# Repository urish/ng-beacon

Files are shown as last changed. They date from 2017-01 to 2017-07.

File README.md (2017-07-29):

# ng-beacon

[Physical Web Beacon](https://medium.com/@urish/exploring-the-physical-web-without-buying-beacons-efae51e36c2e) shaped after the [Angular](https://angular.io) logo with JavaScript support

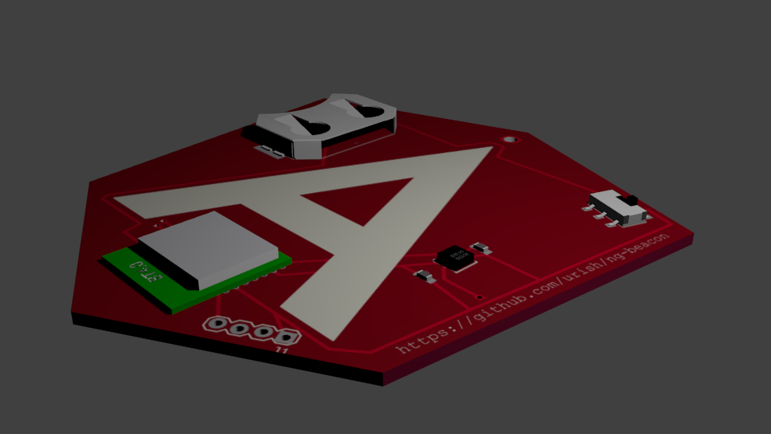
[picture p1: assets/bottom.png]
ng-beacon bottom view


Copyright (C) 2016, 2017 Uri Shaked

## Build your own beacon

Check out the [BOM](BOM.md) file for the list of materials. In addition, you need to get the [PCB](hardware/) printed, I got mine from [PCBWay](http://www.pcbway.com).

## Features

- Physical Web (Eddystone) Beacon
- iBeacon
- Built-in [JavaScript Interpreter](https://www.espruino.com/Reference)
- Fully programmable via JavaScript
- Over-the-air firmware updates
- Prototyping area where you can add your own sensors and extend the board
- Runs of CR2032 / CR2024 coin cell battery, can last for several months
- Built in LED and push button

## Hardware
The board uses the [nRF52832 chip](https://www.nordicsemi.com/eng/Products/Bluetooth-low-energy/nRF52832), which has the following features:

- 32-bit ARM Cortex-M4F Processor running at 64MHz
- 512kB flash + 64kB RAM
- Bluetooth 5 support, up to 2MBPS
- Up to +4dBm output power, -96dBm sensitivity
- 3 PWM, 3 SPI, 2 I²C, Serial UART

## Code samples

Configure the built-in button to control the LED:

    setWatch(() => LED1.toggle(), BTN1, { 
      repeat: true,
      edge: 'falling', 
      debounce: 100
    });

[More code samples](examples/)

## Firmware

The current firmware is based on [Espruino](espruino.com). The latest source code [can be found here](https://github.com/urish/Espruino/tree/ng-beacon), and the most recent firmware build can be found in [this repo](https://github.com/urish/ng-beacon-firmware).

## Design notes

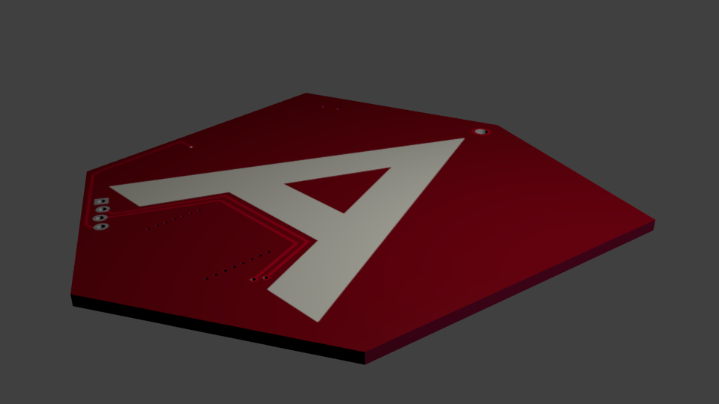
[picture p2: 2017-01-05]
assets/top.png

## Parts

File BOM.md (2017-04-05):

# ng-beacon BOM

| Name | Quantity | Price | Order Link | Comment |
|---|---|---|---|---|
| PTR5618 | 1 | 4.65$ | [Taobao](https://world.taobao.com/item/541222748619.htm?spm=a312a.7700714.0.0.PJ33KO#detail) | BLE + MCU |
| SMD Tab CR2032 Battery Holder (SMD) | 1 | 0.24$ | [AliExpress](https://www.aliexpress.com/item/50pcs-SMD-Tab-20mm-CR2032-2032-Battery-Button-Cell-Holder-Coin-Cell-Retainer-Battery-Holder-surface/32732961416.html) |  |
| DPDT Switch | 1 | 0.16$ | [AliExpress](https://www.aliexpress.com/item/100-pcs-Miniature-Slide-Switch-6-Pin-2P2T-DPDT-ON-ON-Surface-Mount-SMT-SMD-PCB/32759082251.html) |  |
| CR2032 Battery | 1 | 0.19$ | [AliExpress](https://www.aliexpress.com/item/10pcs-lot-CR2032-Lithium-Button-Cell-Batteries-ECR2032-DL2032-KCR2032-EE6227-3V-220mAh-Rohs/32648145261.html) |  |
| SHT20 | Optional | 1.7$ | [AliExpress](https://www.aliexpress.com/item/10pcs-lot-SHT20-Temperature-And-Humidity-Sensor/1916310064.html) | Temperature Sensor |

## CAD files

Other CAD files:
models/DFN6_SHT.skp
models/PTR5518.skp

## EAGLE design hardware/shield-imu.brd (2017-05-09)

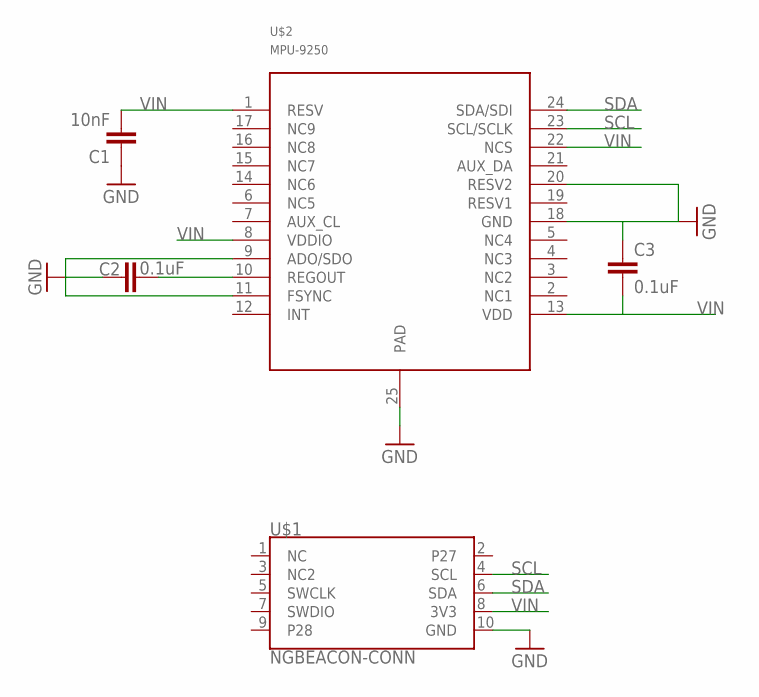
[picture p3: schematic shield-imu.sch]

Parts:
C1: 10nF; 0603-CAP
C2, C3: 0.1uF; 0603-CAP
U$1: NGBEACON-CONN; 2X5-PTH-1.27MM
U$2: MPU-9250; LEAD-QFN24

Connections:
GND: C1.1, C2.1, C3.1, U$1.10 (GND), U$2.9 (ADO/SDO), U$2.11 (FSYNC), U$2.18 (GND), U$2.20 (RESV2), U$2.25 (PAD)
unnamed: C2.2, U$2.10 (REGOUT)
SCL: U$1.4 (SCL), U$2.23 (SCL/SCLK)
SDA: U$1.6 (SDA), U$2.24 (SDA/SDI)
VIN: C1.2, C3.2, U$1.8 (3V3), U$2.1 (RESV), U$2.8 (VDDIO), U$2.13 (VDD), U$2.22 (NCS)

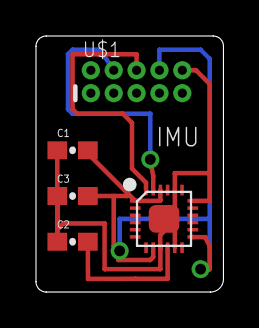
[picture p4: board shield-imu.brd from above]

Board: 2 copper layers, 10.4 x 14.2 mm, 5 parts (0 on the bottom side), 5 nets.

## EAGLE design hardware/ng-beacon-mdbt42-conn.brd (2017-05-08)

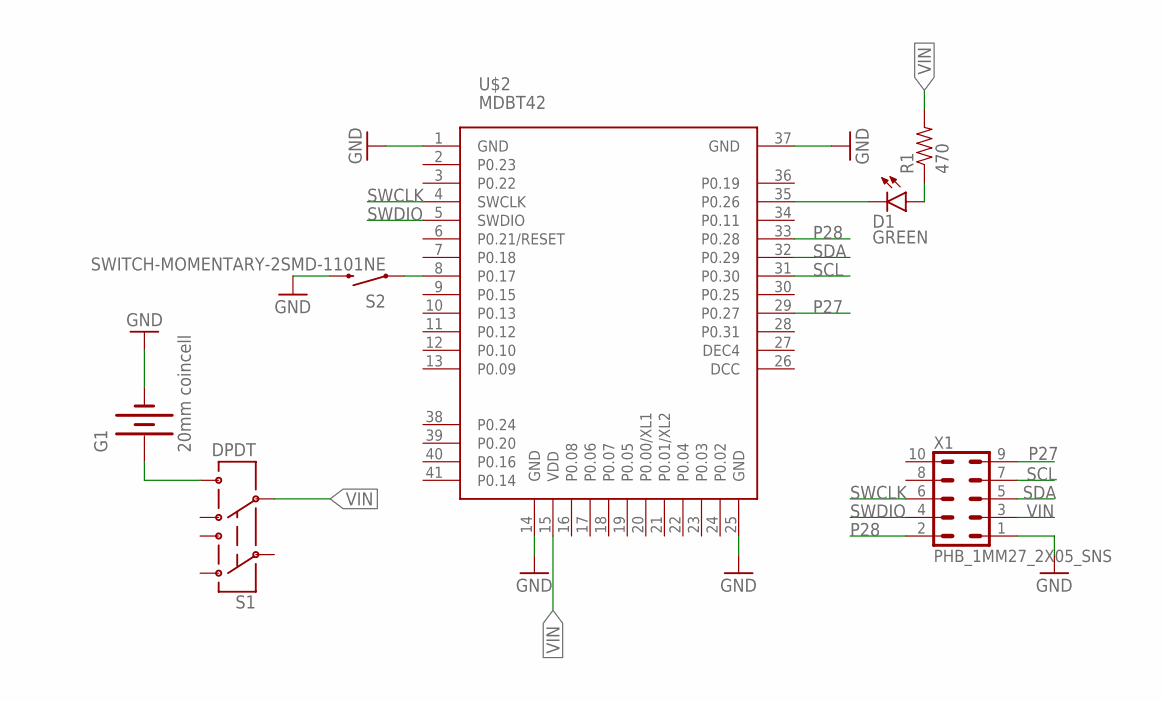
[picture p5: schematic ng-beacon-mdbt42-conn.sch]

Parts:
D1: GREEN; LED-0603
G1: 20mm coincell; BATTCON_20MM_4LEGS
R1: 470; 0603-RES
S1: DPDT; AYZ0202
S2: SWITCH-MOMENTARY-2SMD-1101NE; TACTILE-SWITCH-1101NE
U$2: MDBT42
X1: PHB_1MM27_2X05_SNS

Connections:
GND: G1.NEGATIVE (-), S2.2, U$2.1 (GND), U$2.14 (GND), U$2.25 (GND), U$2.37 (GND), X1.1
unnamed: G1.POSITIVE@1 (+), G1.POSITIVE@2 (+), G1.POSITIVE@3 (+), G1.POSITIVE@4 (+), S1.6
unnamed: S2.1, U$2.8 (P0.17)
unnamed: D1.C, U$2.35 (P0.26)
unnamed: D1.A, R1.1
P27: U$2.29 (P0.27), X1.9
P28: U$2.33 (P0.28), X1.2
SCL: U$2.31 (P0.30), X1.7
SDA: U$2.32 (P0.29), X1.5
SWCLK: U$2.4 (SWCLK), X1.6
SWDIO: U$2.5 (SWDIO), X1.4
VIN: R1.2, S1.5, U$2.15 (VDD), X1.3

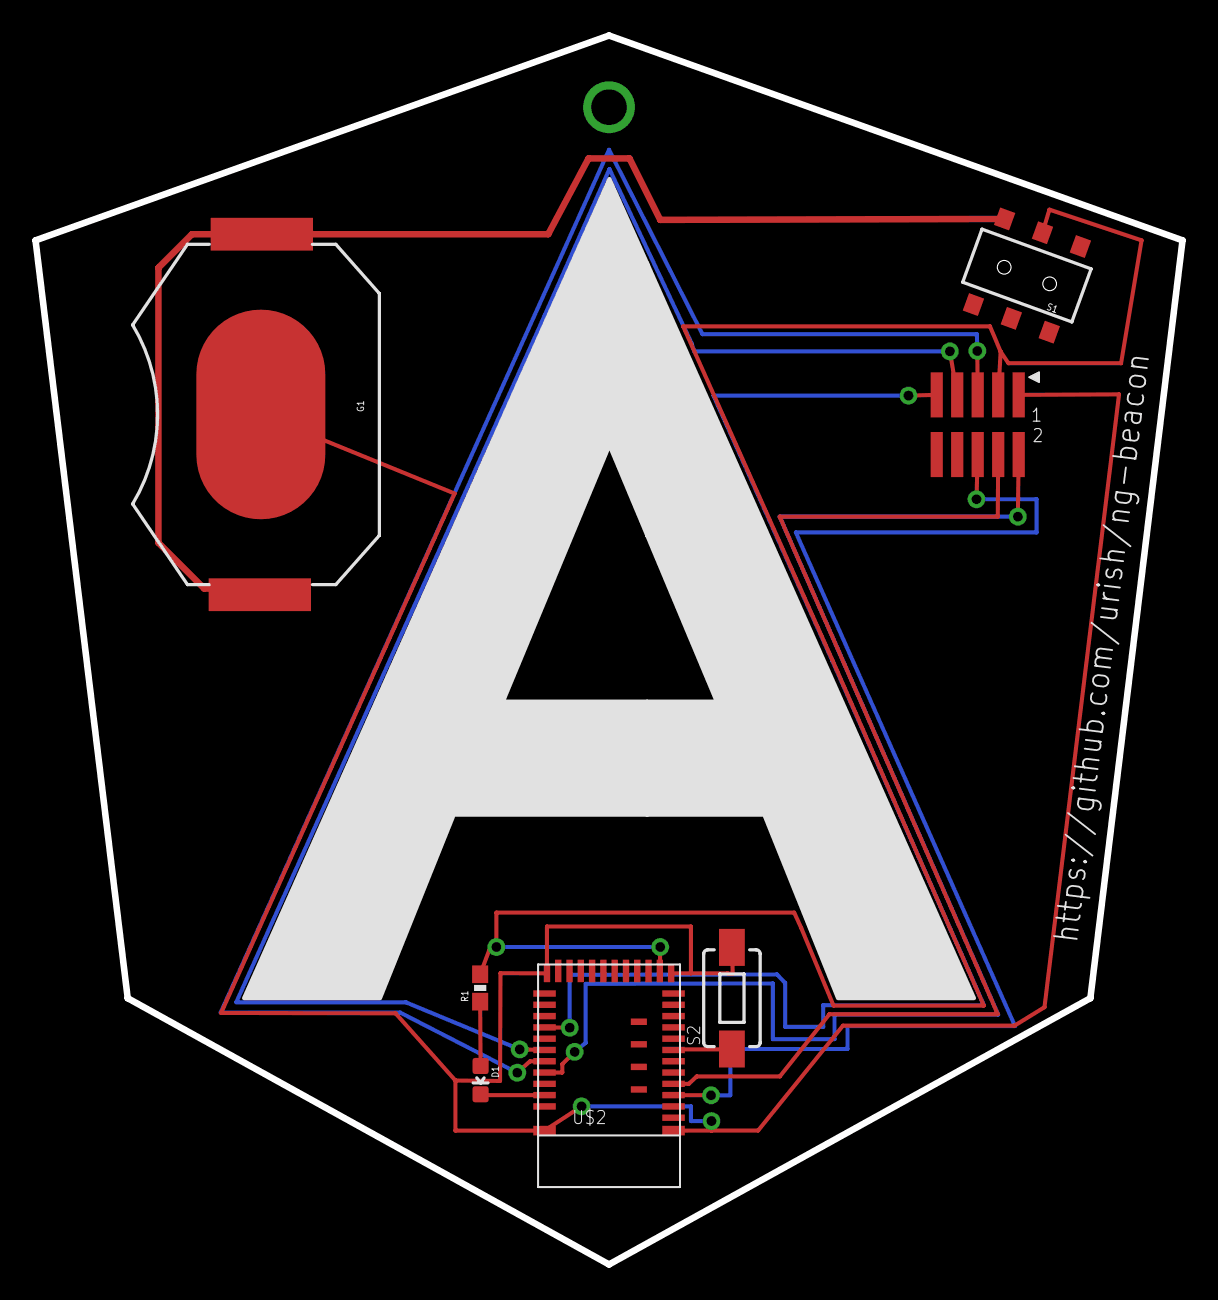
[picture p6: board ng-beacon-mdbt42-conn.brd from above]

Board: 2 copper layers, 71.1 x 76.2 mm, 7 parts (0 on the bottom side), 12 nets.

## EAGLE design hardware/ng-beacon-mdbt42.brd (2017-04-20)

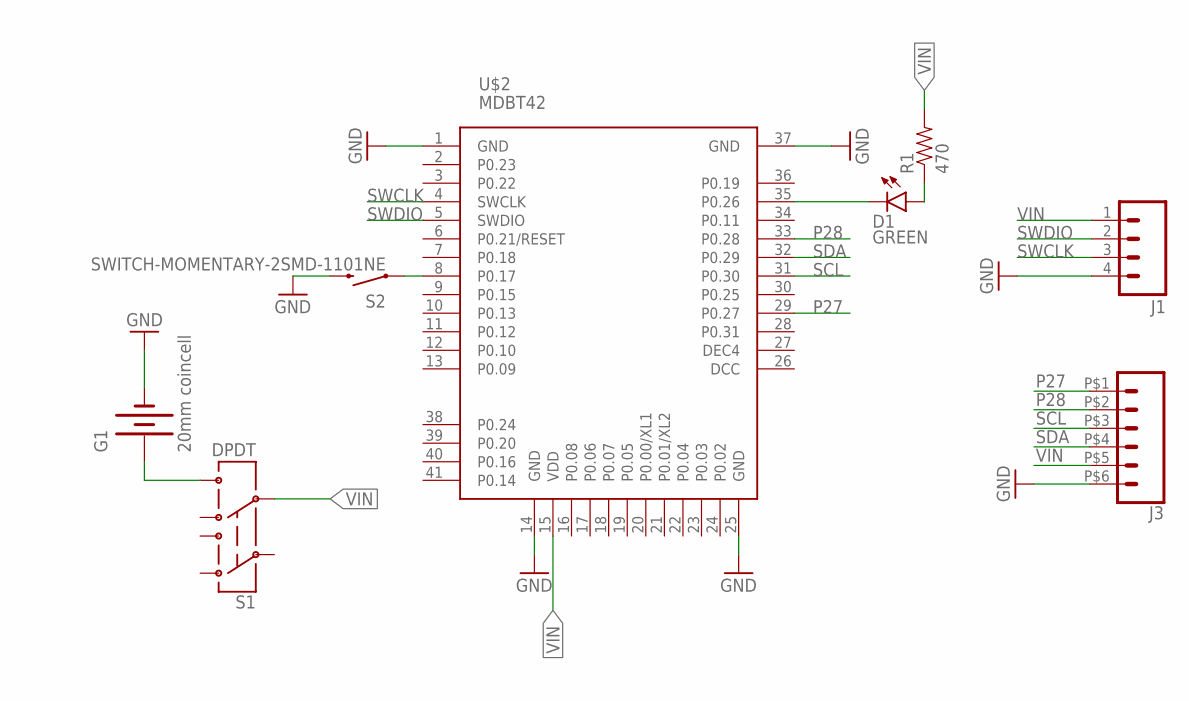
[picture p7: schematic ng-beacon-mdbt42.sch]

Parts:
D1: GREEN; LED-0603
G1: 20mm coincell; BATTCON_20MM_4LEGS
J1: M04LOCK; 1X04_LOCK
J3: CONN_06; PROTO4X6
R1: 470; 0603-RES
S1: DPDT; AYZ0202
S2: SWITCH-MOMENTARY-2SMD-1101NE; TACTILE-SWITCH-1101NE
U$2: MDBT42

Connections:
GND: G1.NEGATIVE (-), J1.4, J3.P$6 (6), S2.2, U$2.1 (GND), U$2.14 (GND), U$2.25 (GND), U$2.37 (GND)
unnamed: G1.POSITIVE@1 (+), G1.POSITIVE@2 (+), G1.POSITIVE@3 (+), G1.POSITIVE@4 (+), S1.6
unnamed: S2.1, U$2.8 (P0.17)
unnamed: D1.C, U$2.35 (P0.26)
unnamed: D1.A, R1.1
P27: J3.P$1 (1), U$2.29 (P0.27)
P28: J3.P$2 (2), U$2.33 (P0.28)
SCL: J3.P$3 (3), U$2.31 (P0.30)
SDA: J3.P$4 (4), U$2.32 (P0.29)
SWCLK: J1.3, U$2.4 (SWCLK)
SWDIO: J1.2, U$2.5 (SWDIO)
VIN: J1.1, J3.P$5 (5), R1.2, S1.5, U$2.15 (VDD)

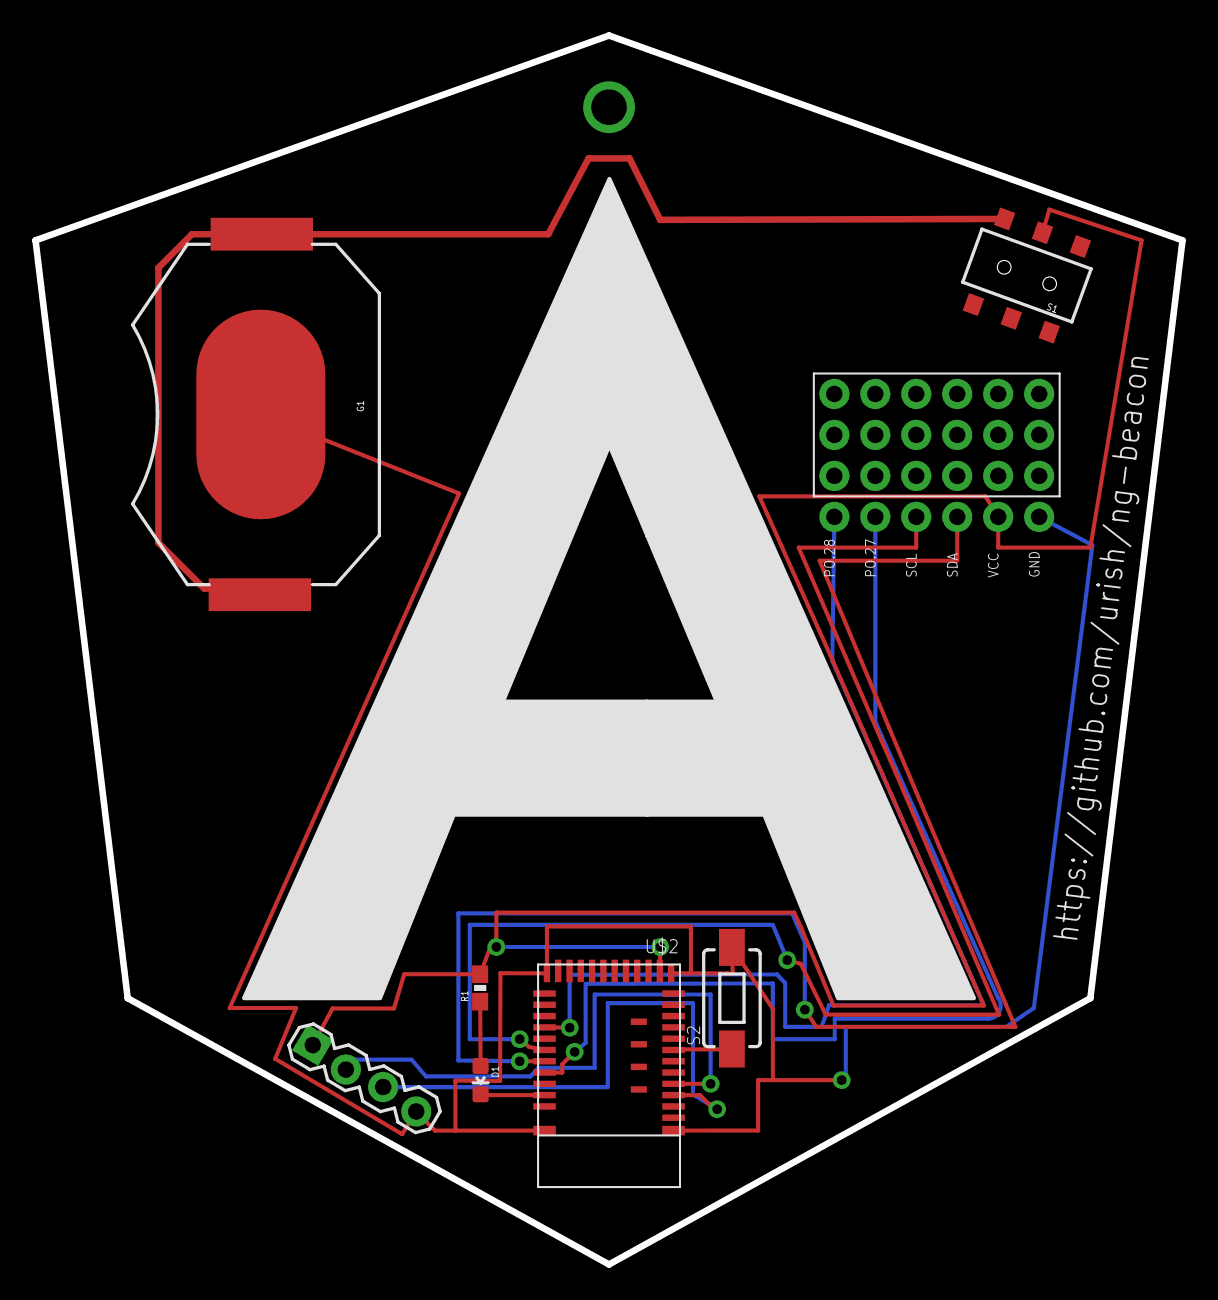
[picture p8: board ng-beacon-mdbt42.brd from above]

Board: 2 copper layers, 71.1 x 76.2 mm, 8 parts (0 on the bottom side), 12 nets.

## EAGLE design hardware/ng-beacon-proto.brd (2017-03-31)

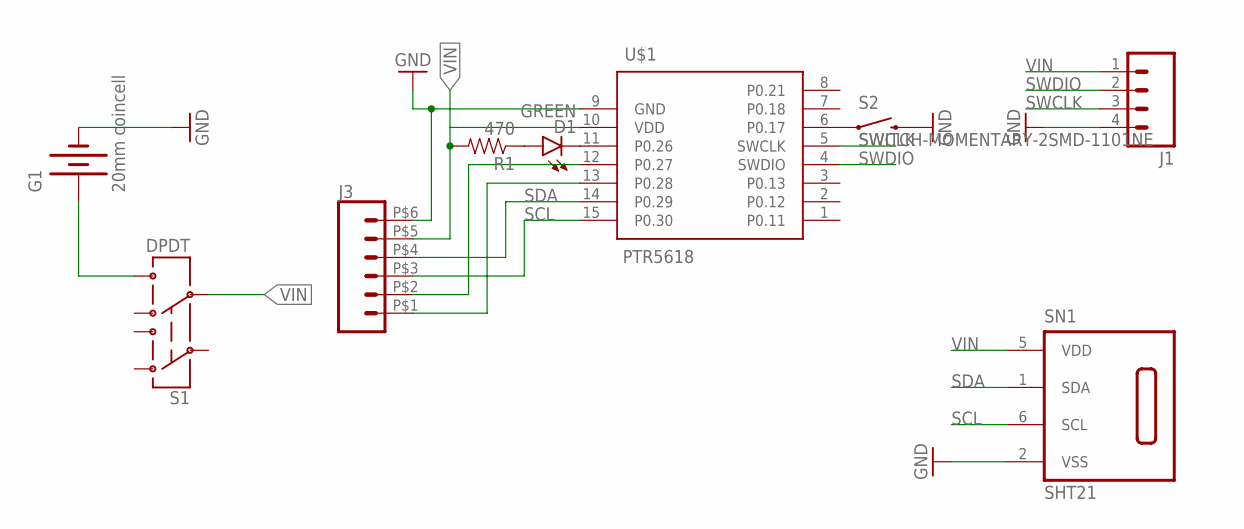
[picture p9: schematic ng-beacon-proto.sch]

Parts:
D1: GREEN; LED-0603
G1: 20mm coincell; BATTCON_20MM_4LEGS
J1: M04LOCK; 1X04_LOCK
J3: CONN_06; PROTO4X6
R1: 470; 0603-RES
S1: DPDT; AYZ0202
S2: SWITCH-MOMENTARY-2SMD-1101NE; TACTILE-SWITCH-1101NE
SN1: SHT21; DFN6/SHT
U$1: PTR5618; PTR5518

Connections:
GND: G1.NEGATIVE (-), J1.4, J3.P$6 (6), S2.2, SN1.2 (VSS), U$1.9 (GND)
unnamed: G1.POSITIVE@1 (+), G1.POSITIVE@2 (+), G1.POSITIVE@3 (+), G1.POSITIVE@4 (+), S1.6
unnamed: S2.1, U$1.6 (P0.17)
unnamed: J3.P$2 (2), U$1.12 (P0.27)
unnamed: J3.P$1 (1), U$1.13 (P0.28)
unnamed: D1.C, U$1.11 (P0.26)
unnamed: D1.A, R1.1
SCL: J3.P$3 (3), SN1.6 (SCL), U$1.15 (P0.30)
SDA: J3.P$4 (4), SN1.1 (SDA), U$1.14 (P0.29)
SWCLK: J1.3, U$1.5 (SWCLK)
SWDIO: J1.2, U$1.4 (SWDIO)
VIN: J1.1, J3.P$5 (5), R1.2, S1.5, SN1.5 (VDD), U$1.10 (VDD)

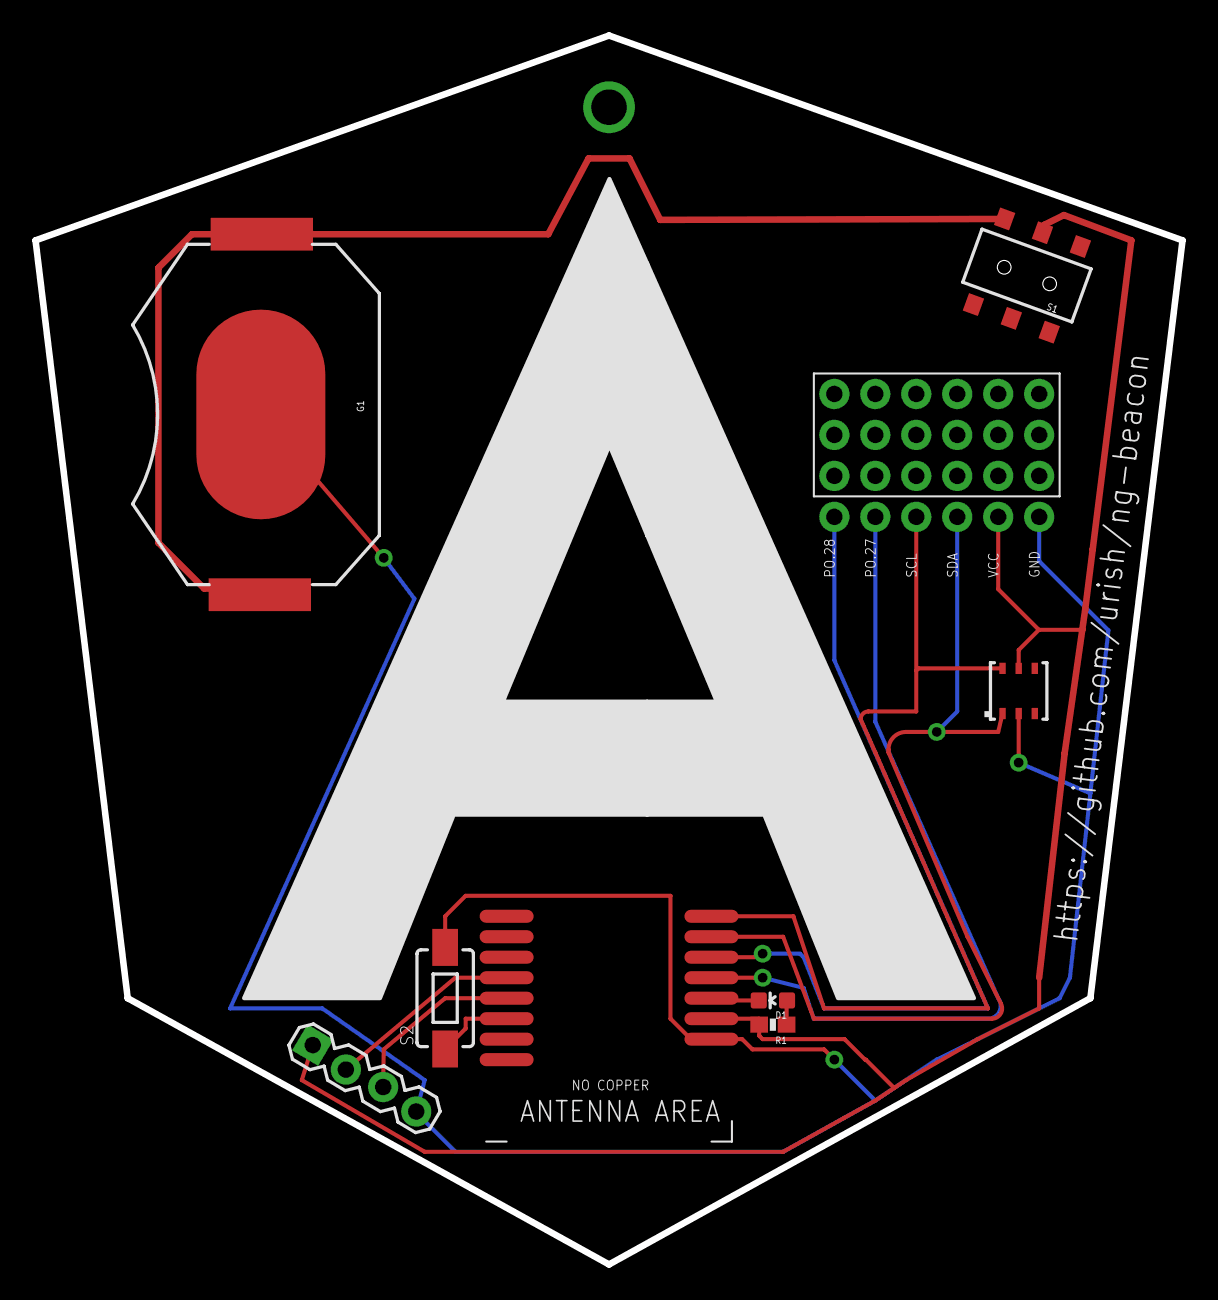
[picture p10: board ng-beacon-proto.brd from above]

Board: 2 copper layers, 71.1 x 76.2 mm, 9 parts (0 on the bottom side), 12 nets.

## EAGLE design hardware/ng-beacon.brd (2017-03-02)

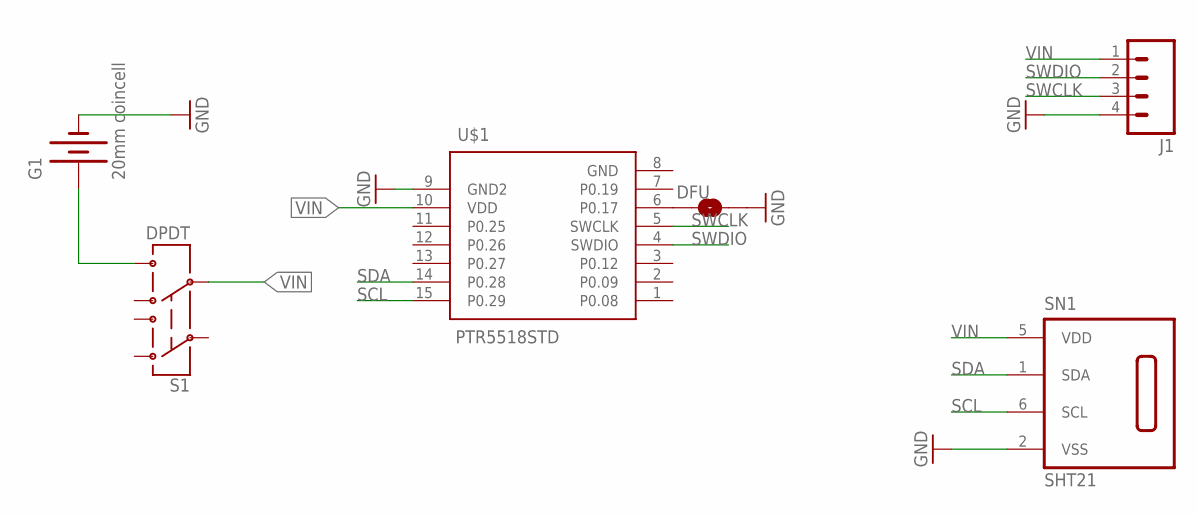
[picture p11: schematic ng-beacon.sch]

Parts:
DFU: JUMPER-PAD-2-NO; PAD-JUMPER-2-NO_NO_SILK
G1: 20mm coincell; BATTCON_20MM_4LEGS
J1: M04LOCK; 1X04_LOCK
S1: DPDT; AYZ0202
SN1: SHT21; DFN6/SHT
U$1: PTR5518STD; PTR5518

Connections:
GND: DFU.2, G1.NEGATIVE (-), J1.4, SN1.2 (VSS), U$1.8 (GND), U$1.9 (GND2)
unnamed: G1.POSITIVE@1 (+), G1.POSITIVE@2 (+), G1.POSITIVE@3 (+), G1.POSITIVE@4 (+), S1.6
unnamed: DFU.1, U$1.6 (P0.17)
SCL: SN1.6 (SCL), U$1.15 (P0.29)
SDA: SN1.1 (SDA), U$1.14 (P0.28)
SWCLK: J1.3, U$1.5 (SWCLK)
SWDIO: J1.2, U$1.4 (SWDIO)
VIN: J1.1, S1.5, SN1.5 (VDD), U$1.10 (VDD)

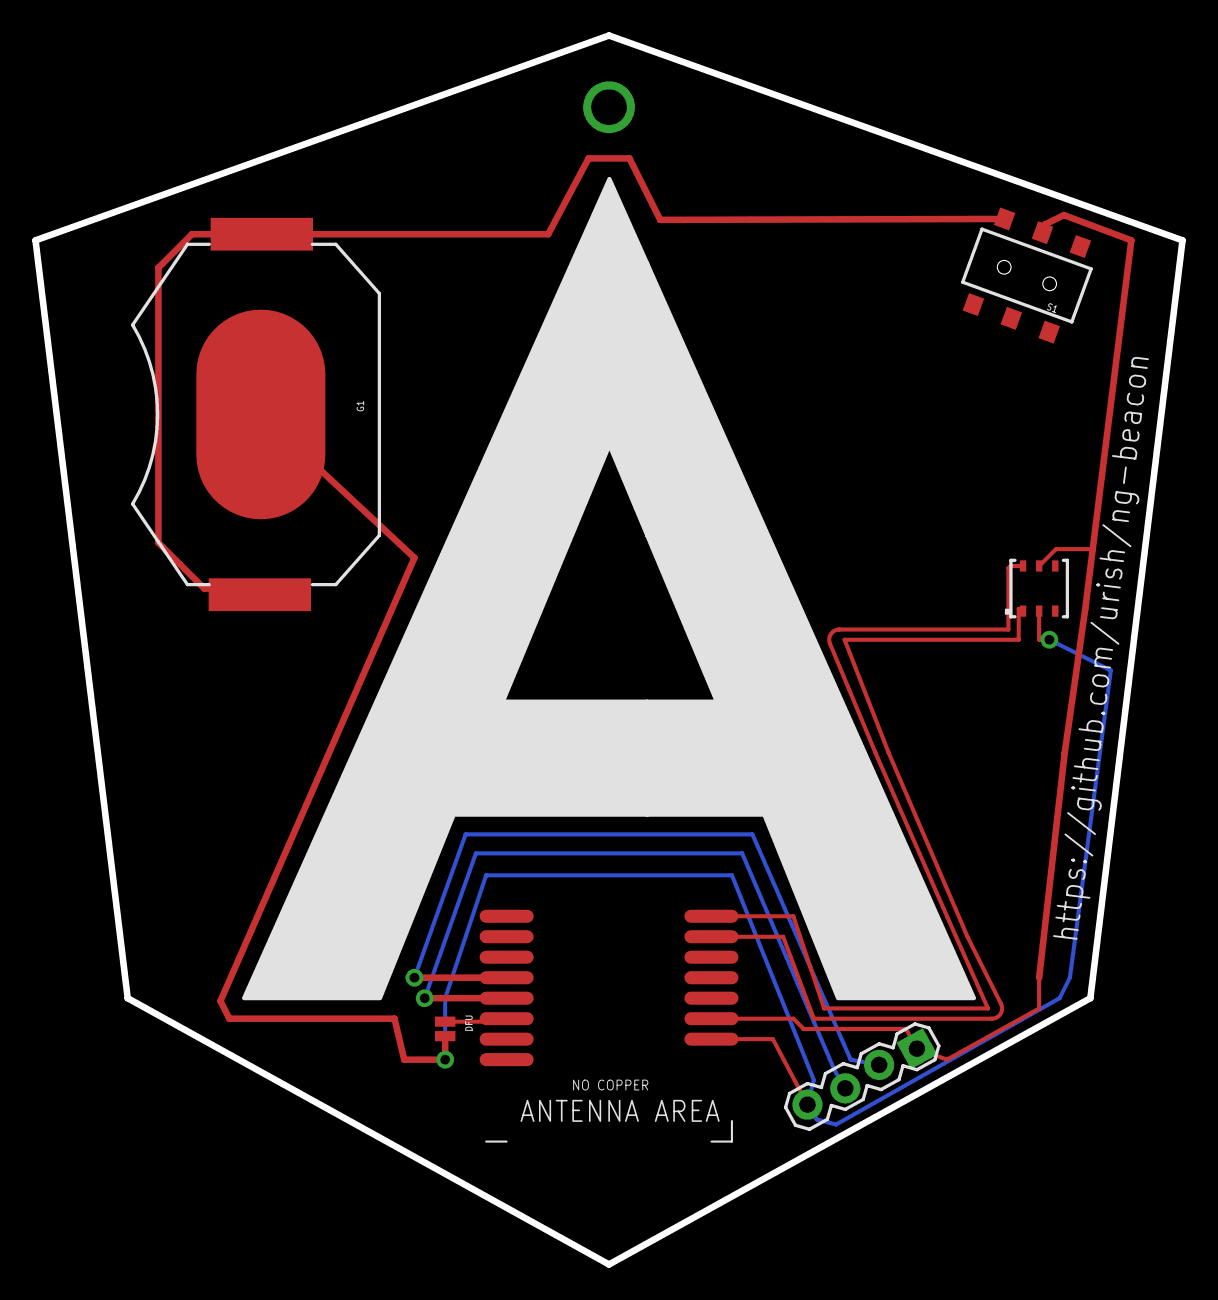
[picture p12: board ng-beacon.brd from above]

Board: 2 copper layers, 71.1 x 76.2 mm, 6 parts (0 on the bottom side), 8 nets.

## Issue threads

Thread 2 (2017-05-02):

OnBoard Programmer

denzelwamburu, 2017-05-02:
Can we have an onboard programmer, probably a JTAG?
I've made a fork and am working on the changes.

Regards.

urish, 2017-05-02:
Hi @denzelwamburu! It is currently possible to program using either over the air DFU (see [here](https://github.com/urish/ng-beacon-firmware) for instructions) or using the 4-pin header connector that exposes the ARM serial programming interface. The pin out is similar to the one found in [this J-Link programmer](https://www.aliexpress.com/item/NEW-OB-ARM-Debugger-Programmer-Downloader-Replace-V8-SWD-M74/32670918773.html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) which I am using the program my board.

That said, I am considering replacing it with a more standard [Cortex M debug connector](http://cfile24.uf.tistory.com/image/140CEE1E4CE1F5BA320197) in the future. What are you currently working on?

denzelwamburu, 2017-05-02:
My idea was to integrate the debugger on board as well as a coin cell charger to harness power from the usb connection. This would be helpful in field applications. My main aim was adding the charger but also felt i could play around with the idea of the debugger.

urish, 2017-05-02:
Sounds cool!

I had an idea of replacing the coin cell with a super capacitor + adding USB charging. I built a small prototype. Charging was super quick (just a few seconds), but it could only last an hour or so on a single charge, which was too limited in my opinion.

Are CR2032 lithium cells rechargeable? Or would you need to replace it with a lithium-ion cell?

denzelwamburu, 2017-05-02:
We need to replace,here are some models that are rechargable
https://www.sparkfun.com/products/11928
http://www.ebay.co.uk/itm/2-x-3-6V-LiR2032-Rechargeable-Coin-Button-Cell-Battery-Li-ion-replace-CR2032-UK-/400871754904

An example circuit: https://oshpark.com/shared_projects/Q9b7sRrL

urish, 2017-05-02:
Awesome!

Seems like the rechargeable ones are 3V6, which means we also need to drop down the voltage. If I recall well, 3.6 is the top limit of nRF52, and these batteries probably deliver more than that when fully charged

denzelwamburu, 2017-05-02:
Yeah, an extra resistor ? 😬

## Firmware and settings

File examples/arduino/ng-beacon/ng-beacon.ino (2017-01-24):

/**
 * ng-beacon Physical Web Firmware 
 *
 * Copyright (C) 2017, Uri Shaked. Published under MIT license.
 *
 * This sketch uses the following libraries:
 * - https://github.com/sandeepmistry/arduino-nRF5
 * - https://github.com/sandeepmistry/arduino-BLEPeripheral
*/

#include <EddystoneBeacon.h>
#include <Wire.h>
#include <Sodaq_SHT2x.h>

// The following are standard BLE services / characteristics:
#define UUID_ENVIRONMENTAL_SENSING_SERVICE "181A"
#define UUID_TEMPERATURE_CHARACTERISTIC "2A6E"
#define UUID_HUMIDITY_CHARACTERISTIC "2A6F"

EddystoneBeacon beacon = EddystoneBeacon();

BLEService envService = BLEService(UUID_ENVIRONMENTAL_SENSING_SERVICE);
BLEShortCharacteristic tempCharacteristic = BLEShortCharacteristic(UUID_TEMPERATURE_CHARACTERISTIC, BLERead | BLENotify);
BLEUnsignedShortCharacteristic humidityCharacteristic = BLEUnsignedShortCharacteristic(UUID_HUMIDITY_CHARACTERISTIC, BLERead | BLENotify);

void sensorHandler() {
  tempCharacteristic.setValue((int16_t)(SHT2x.GetTemperature() * 100));
  humidityCharacteristic.setValue((uint16_t)(SHT2x.GetHumidity() * 100));
}

void setup() {
  beacon.setAdvertisingInterval(50);
  beacon.setTxPower(-4);
  beacon.setLocalName("ng-beacon");
  beacon.setConnectable(true);
  beacon.setAdvertisedServiceUuid(envService.uuid());
  beacon.addAttribute(envService);
  beacon.addAttribute(tempCharacteristic);
  beacon.addAttribute(humidityCharacteristic);
  beacon.begin(-4, "https://goo.gl/Clzfv7");
  
  Wire.begin();
}

unsigned long lastReading = 0;
void loop() {
  beacon.loop();
  if (beacon.central() && (millis() - lastReading > 500)) {
    sensorHandler();
    lastReading = millis();
  }
}

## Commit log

2016-12-27 update board layout
    [ng-beacon.brd]
2016-12-27 add switch
    [ng-beacon.brd, ng-beacon.sch]
2016-12-27 add programming port
    [ng-beacon.brd, ng-beacon.sch]
2016-12-27 add temperature sensor
    [ng-beacon.brd, ng-beacon.sch]
2016-12-31 fix github repo url text
    [ng-beacon.brd]
2017-01-01 replace battery connector
    [ng-beacon.brd, ng-beacon.sch]
2017-01-01 Add sketchup model of SHT20
    [DFN6_SHT.skp]
2017-01-01 add sketchup model of PTR5518
    [PTR5518.skp]
2017-01-01 remove temp sensor label
    [ng-beacon.brd]
2017-01-05 remove drills from PTR5518 package
    [ng-beacon.brd, ng-beacon.sch]
2017-01-05 improve routing, switch to SparkFun DRU
    [ng-beacon.brd]
2017-01-24 feat(firmware): temperature sensor support
2017-01-31 refactor: move pcb files to `hardware` directory
    [ng-beacon.brd, ng-beacon.sch]
2017-01-31 DOC: update README, add BOM
2017-01-31 fix(pcb): remove I2C pullup resistors
    it works fine without them, as the nRF51 has internal pullups
    [ng-beacon.brd, ng-beacon.sch]
2017-02-21 feat: add DFU pads
    [ng-beacon.brd, ng-beacon.sch]
2017-03-02 fix: update board layout for PTR5618
    [ng-beacon.brd, ng-beacon.sch]
2017-03-13 Add a prototype area with PO.26, 27, SDA, and SCL.
    [ng-beacon.brd, ng-beacon.sch]
2017-03-14 Convert to PTR5618, export components to project-specific library.
    [ng-beacon.brd, ng-beacon.sch]
2017-03-16 move the proto version of a different file
    [ng-beacon-proto.brd, ng-beacon-proto.sch, ng-beacon.sch]
2017-03-31 feat: add LED + BUTTON to the proto board
    [ng-beacon-proto.brd, ng-beacon-proto.sch]
2017-04-05 doc: update BOM
2017-04-20 feat: add board layout for the mdbt42 module
    [ng-beacon-mdbt42.brd, ng-beacon-mdbt42.sch]
2017-05-08 feat: add a small on-board connector for shields
    [ng-beacon-mdbt42-conn.brd, ng-beacon-mdbt42-conn.sch]
2017-05-09 feat: IMU shield
    [shield-imu.brd, shield-imu.sch]
2017-05-09 feat: add ng-beacon shield connector to ng-beacon.lbr
2017-05-09 feat: jlink shield
    [shield-jlink.brd, shield-jlink.sch]
2017-07-29 feat: add JavaScript code samples
2017-07-29 doc: Add code samples section to README

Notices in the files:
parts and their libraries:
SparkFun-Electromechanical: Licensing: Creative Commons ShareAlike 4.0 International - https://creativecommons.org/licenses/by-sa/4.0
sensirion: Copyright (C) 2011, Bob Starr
